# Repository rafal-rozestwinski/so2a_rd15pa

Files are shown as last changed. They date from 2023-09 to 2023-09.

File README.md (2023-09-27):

# so2a_rd15pa

Go to the [FULL BOARD](v1/so2a_rd15_pa_v1/) or [MINIMAL BOARD](v1/so2a_rd15_pa_v1-minimal/)

## Images

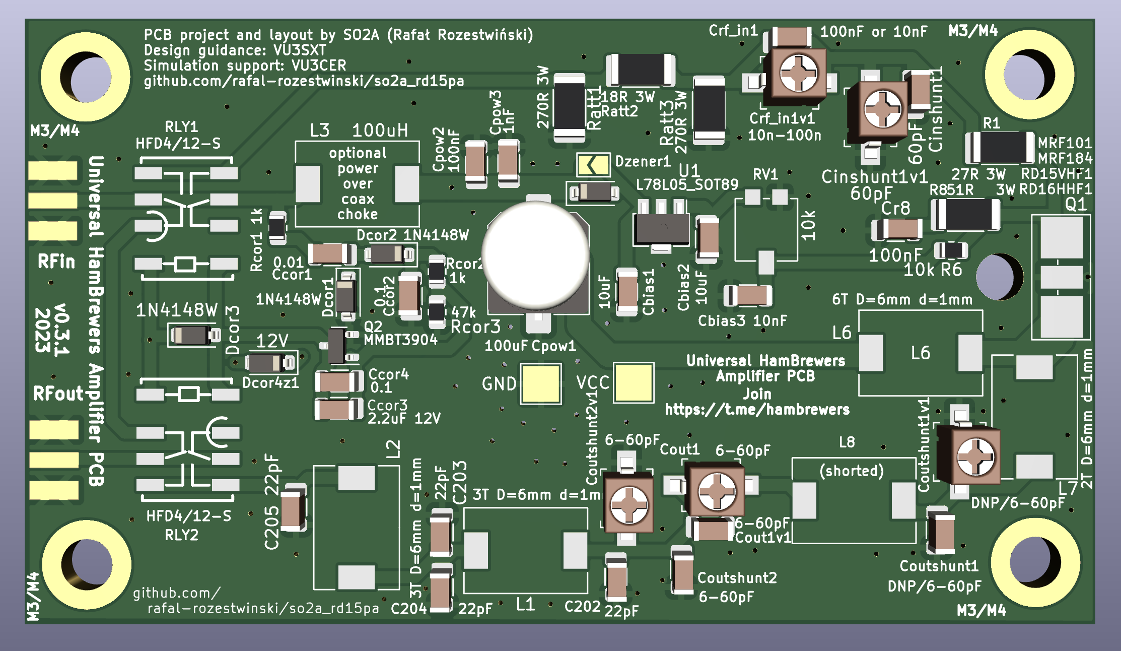
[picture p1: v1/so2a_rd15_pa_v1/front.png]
front


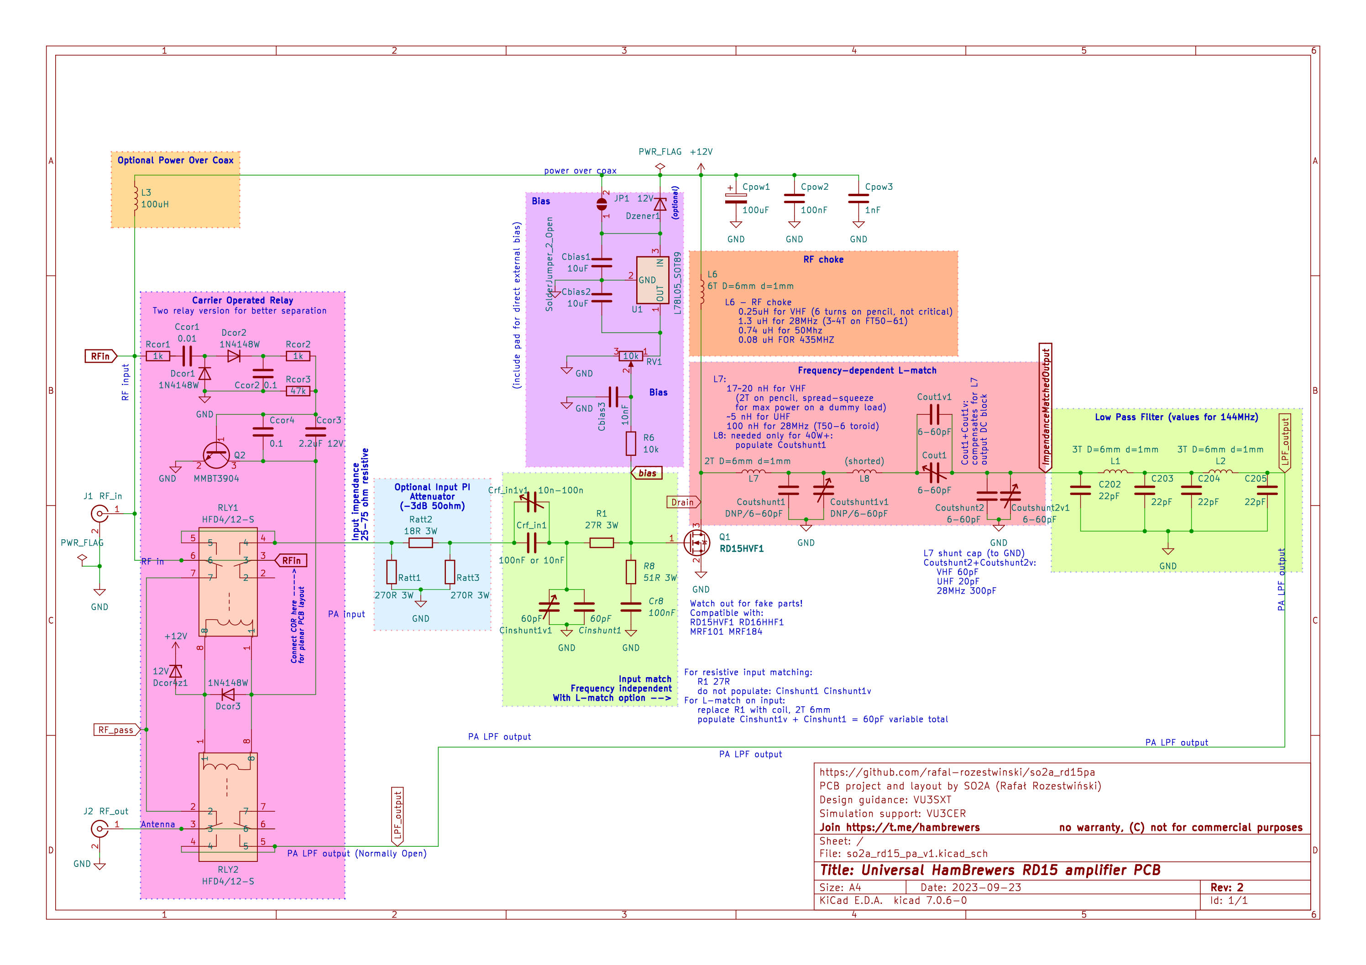
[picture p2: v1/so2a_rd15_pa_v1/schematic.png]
schematic


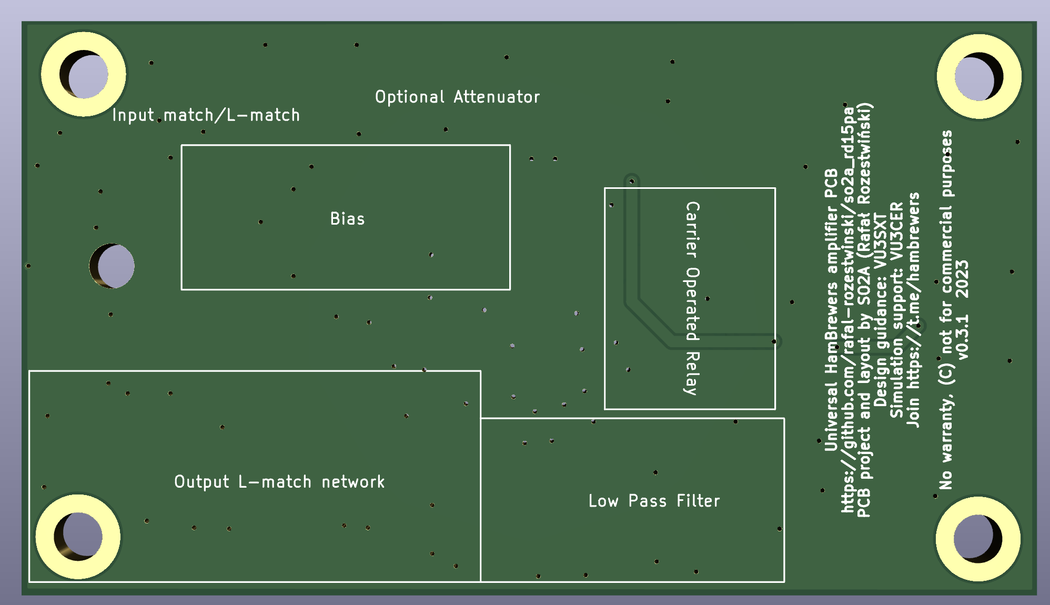
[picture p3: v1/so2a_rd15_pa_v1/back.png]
back


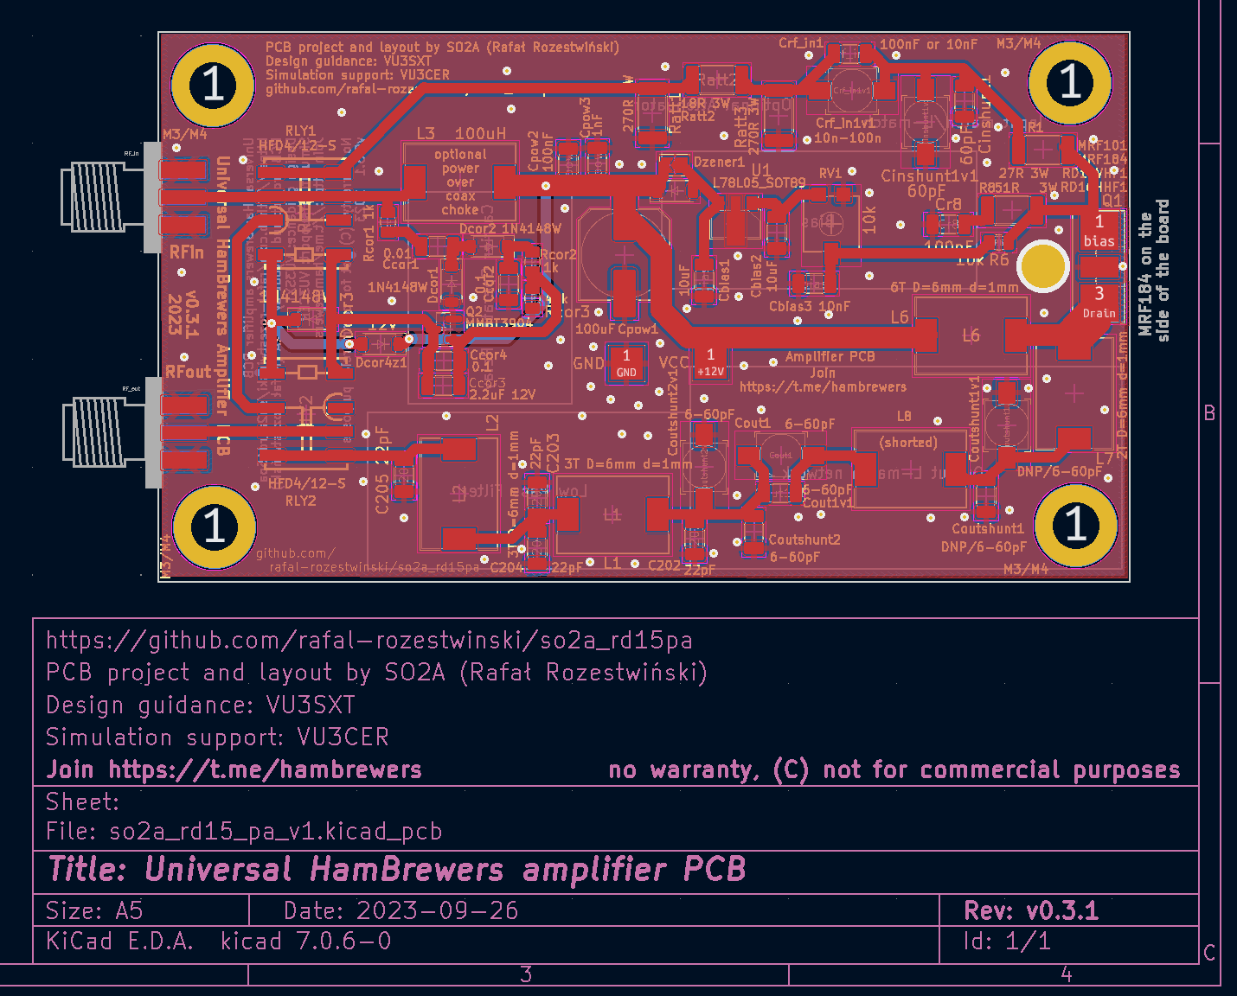
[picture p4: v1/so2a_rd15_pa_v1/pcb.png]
pcb


## Join HamBrewers on Telegram:

http://t.me/hambrewers

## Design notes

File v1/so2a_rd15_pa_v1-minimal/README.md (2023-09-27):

# so2a_rd15pa - MINIMAL

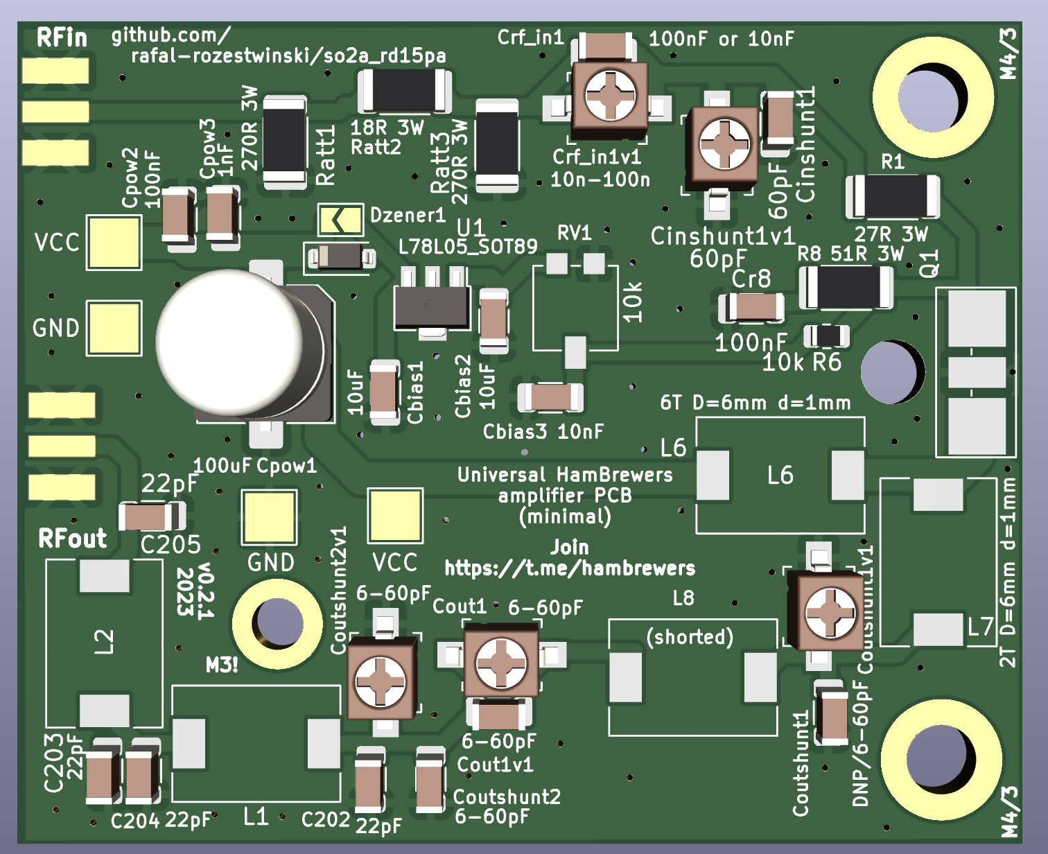
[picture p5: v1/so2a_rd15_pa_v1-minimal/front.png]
front


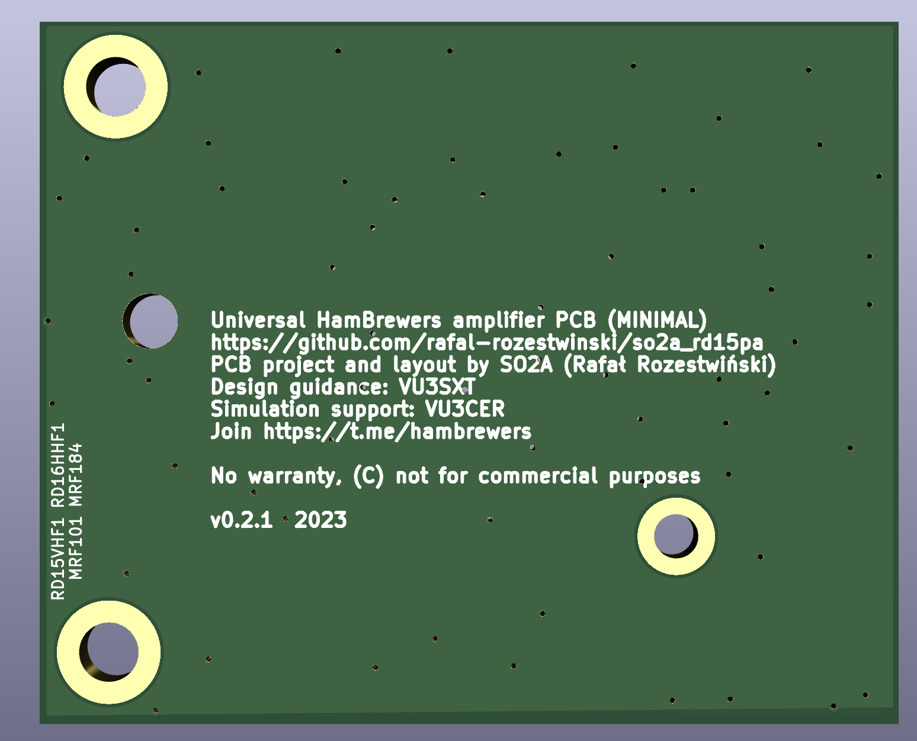
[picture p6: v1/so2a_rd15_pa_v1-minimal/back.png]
back


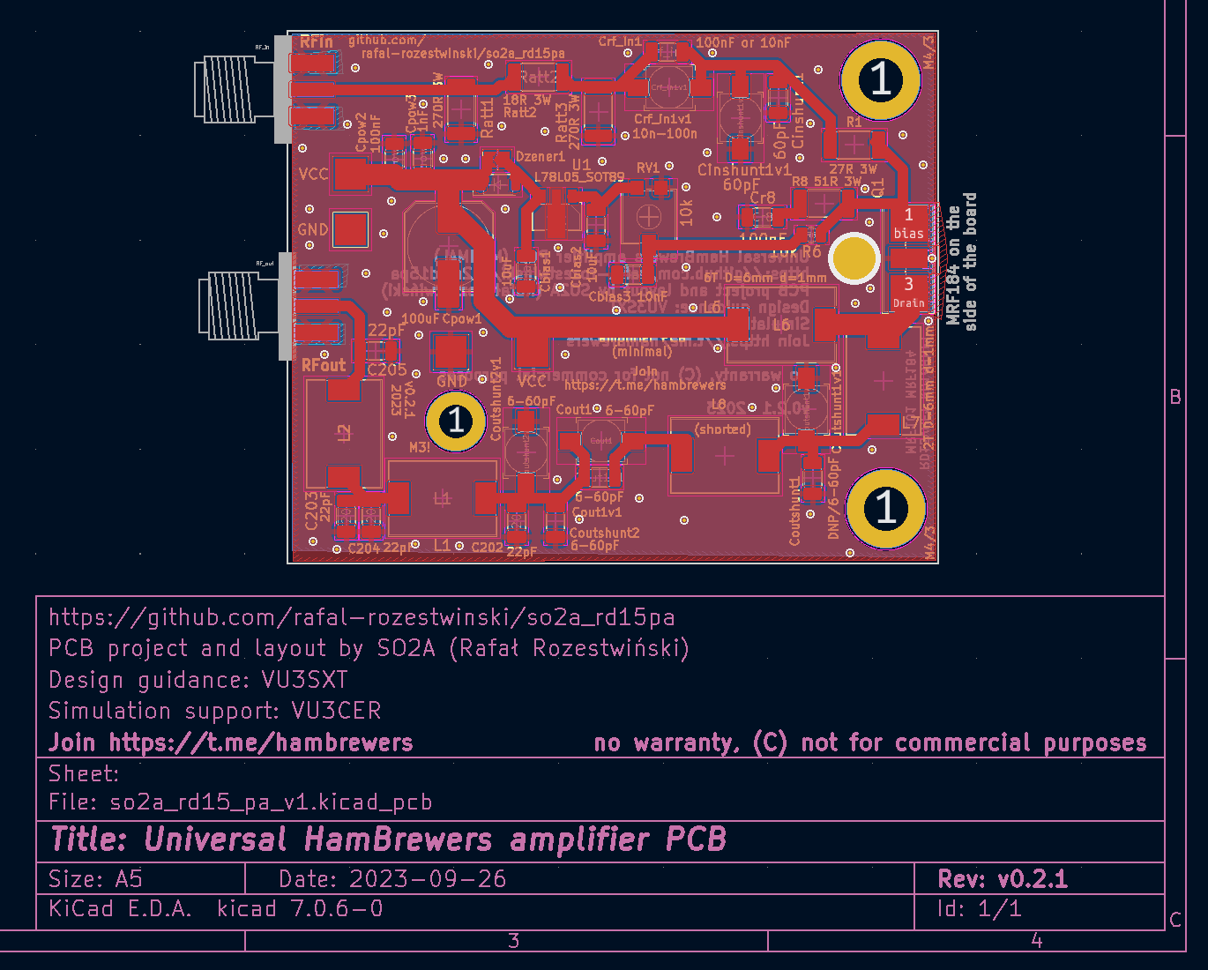
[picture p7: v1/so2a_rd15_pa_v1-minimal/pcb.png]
pcb


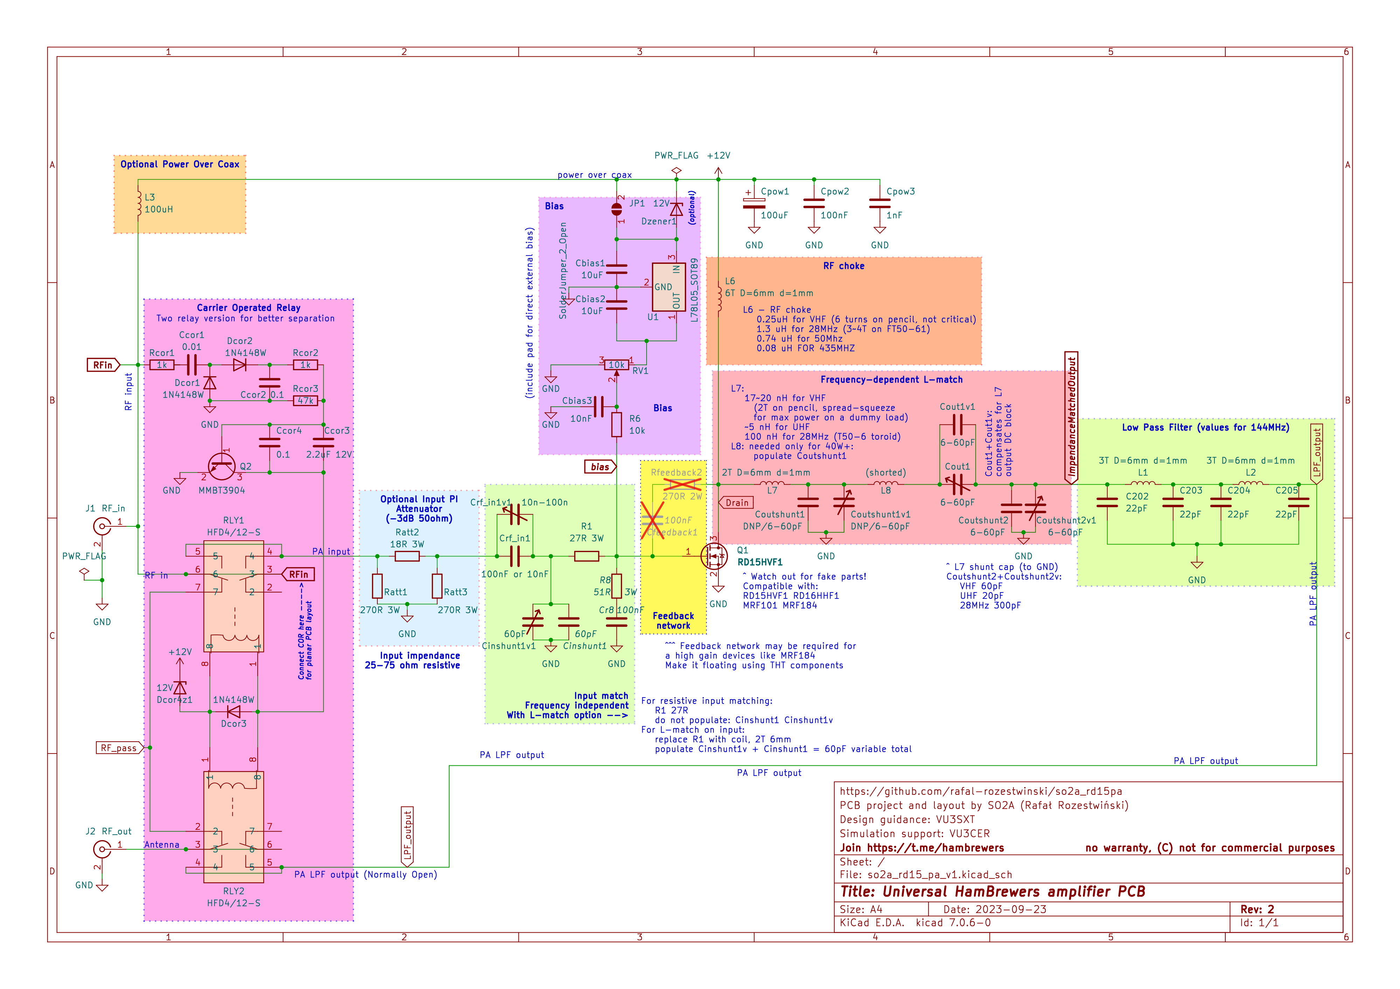
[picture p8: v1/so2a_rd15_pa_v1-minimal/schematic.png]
schematic


## Join HamBrewers on Telegram:

http://t.me/hambrewers

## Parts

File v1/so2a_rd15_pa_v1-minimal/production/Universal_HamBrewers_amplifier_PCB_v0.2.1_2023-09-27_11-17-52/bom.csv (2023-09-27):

Designator | Footprint | Quantity | Value | LCSC Part #
C202, C203, C204, C205 | 1206 | 4 | 22pF
Cbias1, Cbias2 | 1206 | 2 | 10uF
Cbias3 | 1206 | 1 | 10nF
Cinshunt1 | 1206 | 1 | 60pF
Cinshunt1v1 | C_Trimmer_Murata_TZB4-B | 1 | 60pF
Cout1, Coutshunt2v1 | C_Trimmer_Murata_TZB4-B | 2 | 6-60pF
Cout1v1, Coutshunt2 | 1206 | 2 | 6-60pF
Coutshunt1 | 1206 | 1 | DNP/6-60pF
Coutshunt1v1 | C_Trimmer_Murata_TZB4-B | 1 | DNP/6-60pF
Cpow1 | C_Elec_8x10.2 | 1 | 100uF
Cpow2, Cr8 | 1206 | 2 | 100nF
Cpow3 | 1206 | 1 | 1nF
Crf_in1 | 1206 | 1 | 100nF or 10nF
Crf_in1v1 | C_Trimmer_Murata_TZB4-B | 1 | 10n-100n
Dzener1 | D_SOD-123 | 1 | 12V
J1 | SMA_EDGELAUNCH_Modded | 1 | RF_in
J2 | SMA_EDGELAUNCH_Modded | 1 | RF_out
JP1 | SolderJumper-2_P1.3mm_Open_TrianglePad1.0x1.5mm | 1 | SolderJumper_2_Open
L1, L2 | L_Wuerth_HCM-1050 | 2 | 3T D=6mm d=1mm
L6 | L_Wuerth_HCM-1050 | 1 | 6T D=6mm d=1mm
L7 | L_Wuerth_HCM-1050 | 1 | 2T D=6mm d=1mm
L8 | L_Wuerth_HCM-1050 | 1 | (shorted)
Q1 | SO2A_TO-220F-3_Vertical_SMD | 1 | RD15HVF1
R1 | 2010 | 1 | 27R 3W
R6 | 0805 | 1 | 10k
R8 | 2010 | 1 | 51R 3W
RV1 | Potentiometer_Vishay_TS53YL_Vertical | 1 | 10k
Ratt1, Ratt3 | 2010 | 2 | 270R 3W
Ratt2 | 2010 | 1 | 18R 3W
U1 | SOT-89-3 | 1 | L78L05_SOT89

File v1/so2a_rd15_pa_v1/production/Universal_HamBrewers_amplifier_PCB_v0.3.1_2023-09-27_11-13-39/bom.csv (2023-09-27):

Designator | Footprint | Quantity | Value | LCSC Part #
C202, C203, C204, C205 | 1206 | 4 | 22pF
Cbias1, Cbias2 | 1206 | 2 | 10uF
Cbias3 | 1206 | 1 | 10nF
Ccor1 | 1206 | 1 | 0.01
Ccor2, Ccor4 | 1206 | 2 | 0.1
Ccor3 | 1206 | 1 | 2.2uF 12V
Cinshunt1 | 1206 | 1 | 60pF
Cinshunt1v1 | C_Trimmer_Murata_TZB4-B | 1 | 60pF
Cout1, Coutshunt2v1 | C_Trimmer_Murata_TZB4-B | 2 | 6-60pF
Cout1v1, Coutshunt2 | 1206 | 2 | 6-60pF
Coutshunt1 | 1206 | 1 | DNP/6-60pF
Coutshunt1v1 | C_Trimmer_Murata_TZB4-B | 1 | DNP/6-60pF
Cpow1 | C_Elec_8x10.2 | 1 | 100uF
Cpow2, Cr8 | 1206 | 2 | 100nF
Cpow3 | 1206 | 1 | 1nF
Crf_in1 | 1206 | 1 | 100nF or 10nF
Crf_in1v1 | C_Trimmer_Murata_TZB4-B | 1 | 10n-100n
Dcor1, Dcor2, Dcor3 | D_SOD-123 | 3 | 1N4148W
Dcor4z1, Dzener1 | D_SOD-123 | 2 | 12V
J1 | SMA_EDGELAUNCH_Modded | 1 | RF_in
J2 | SMA_EDGELAUNCH_Modded | 1 | RF_out
JP1 | SolderJumper-2_P1.3mm_Open_TrianglePad1.0x1.5mm | 1 | SolderJumper_2_Open
L1, L2 | L_Wuerth_HCM-1050 | 2 | 3T D=6mm d=1mm
L3 | L_Wuerth_HCM-1050 | 1 | 100uH
L6 | L_Wuerth_HCM-1050 | 1 | 6T D=6mm d=1mm
L7 | L_Wuerth_HCM-1050 | 1 | 2T D=6mm d=1mm
L8 | L_Wuerth_HCM-1050 | 1 | (shorted)
Q1 | SO2A_TO-220F-3_Vertical_SMD | 1 | RD15HVF1
Q2 | SOT-23 | 1 | MMBT3904
R1 | 2010 | 1 | 27R 3W
R6 | 0805 | 1 | 10k
R8 | 2010 | 1 | 51R 3W
RLY1, RLY2 | RELAY-SMD_HFD4-XX-SR | 2 | HFD4/12-S | C44212
RV1 | Potentiometer_Vishay_TS53YL_Vertical | 1 | 10k
Ratt1, Ratt3 | 2010 | 2 | 270R 3W
Ratt2 | 2010 | 1 | 18R 3W
Rcor1, Rcor2 | 0805 | 2 | 1k
Rcor3 | 0805 | 1 | 47k
U1 | SOT-89-3 | 1 | L78L05_SOT89

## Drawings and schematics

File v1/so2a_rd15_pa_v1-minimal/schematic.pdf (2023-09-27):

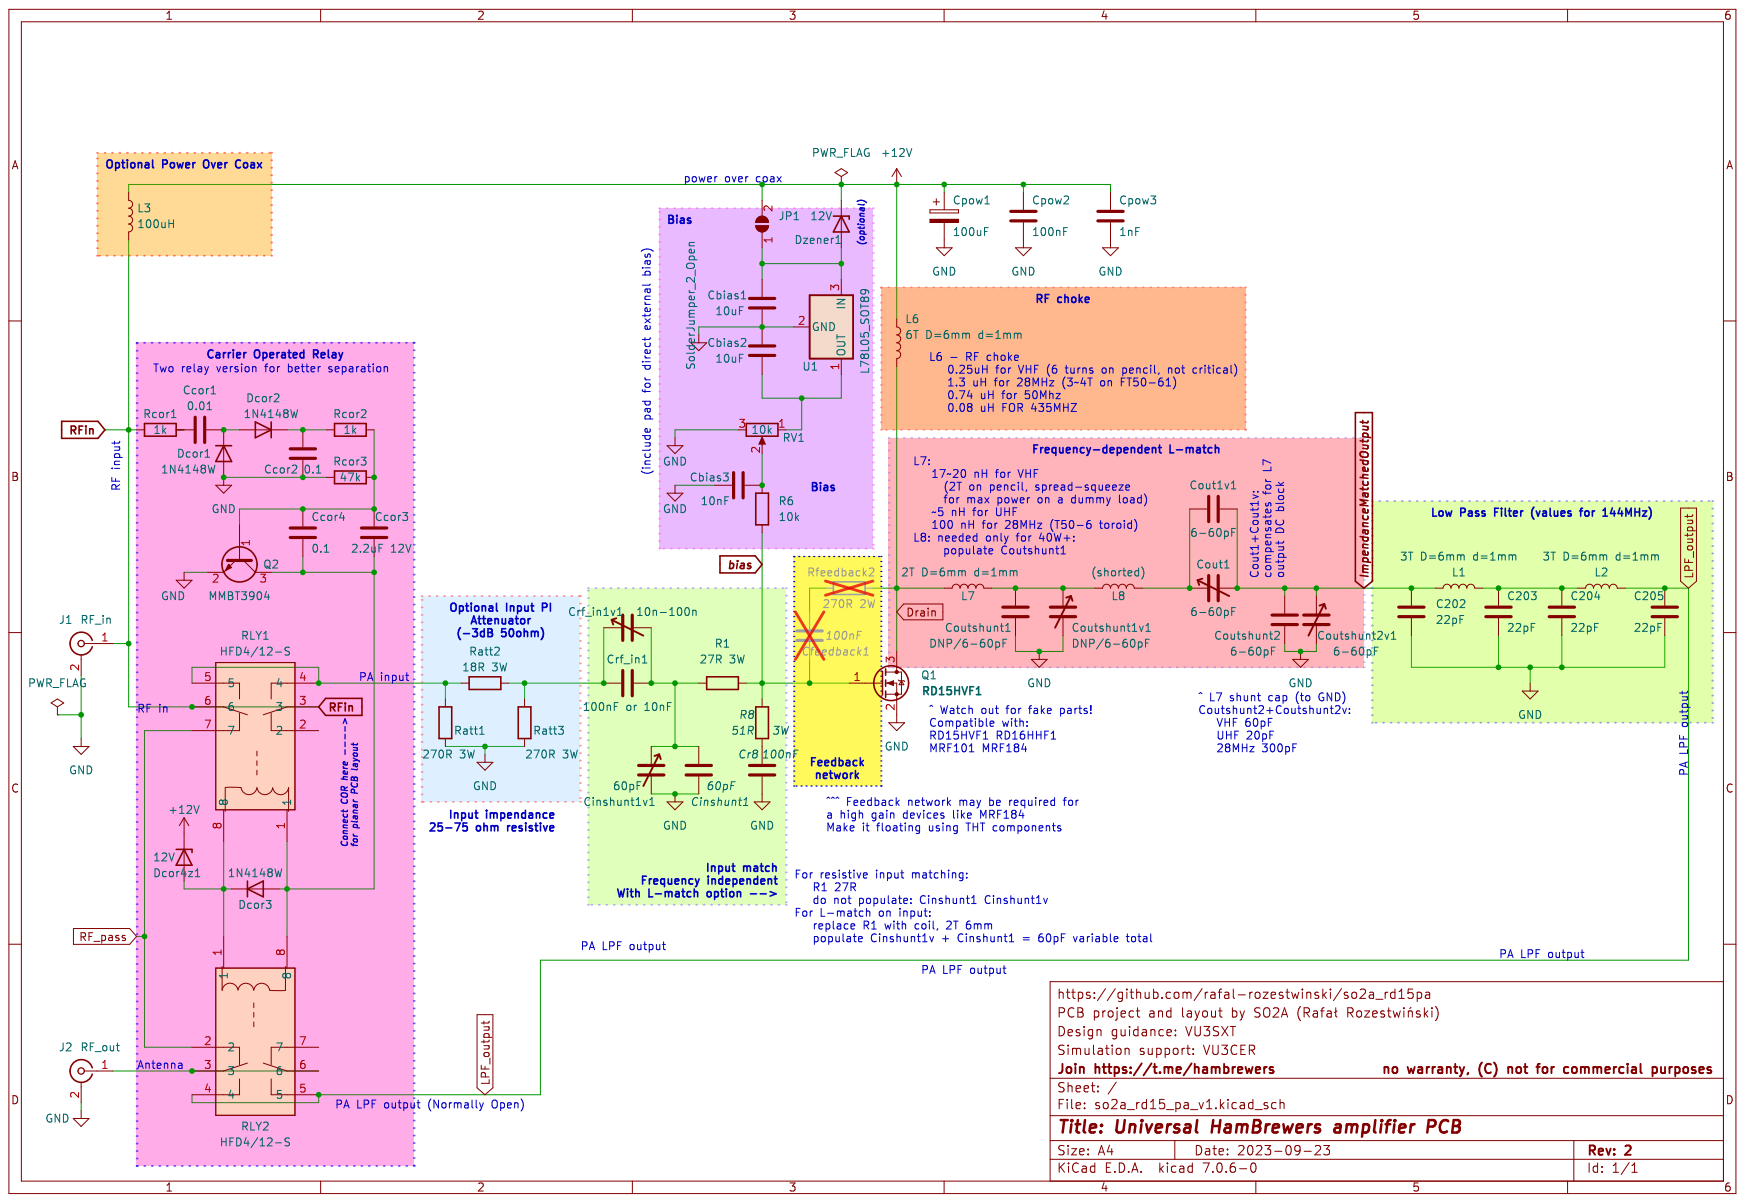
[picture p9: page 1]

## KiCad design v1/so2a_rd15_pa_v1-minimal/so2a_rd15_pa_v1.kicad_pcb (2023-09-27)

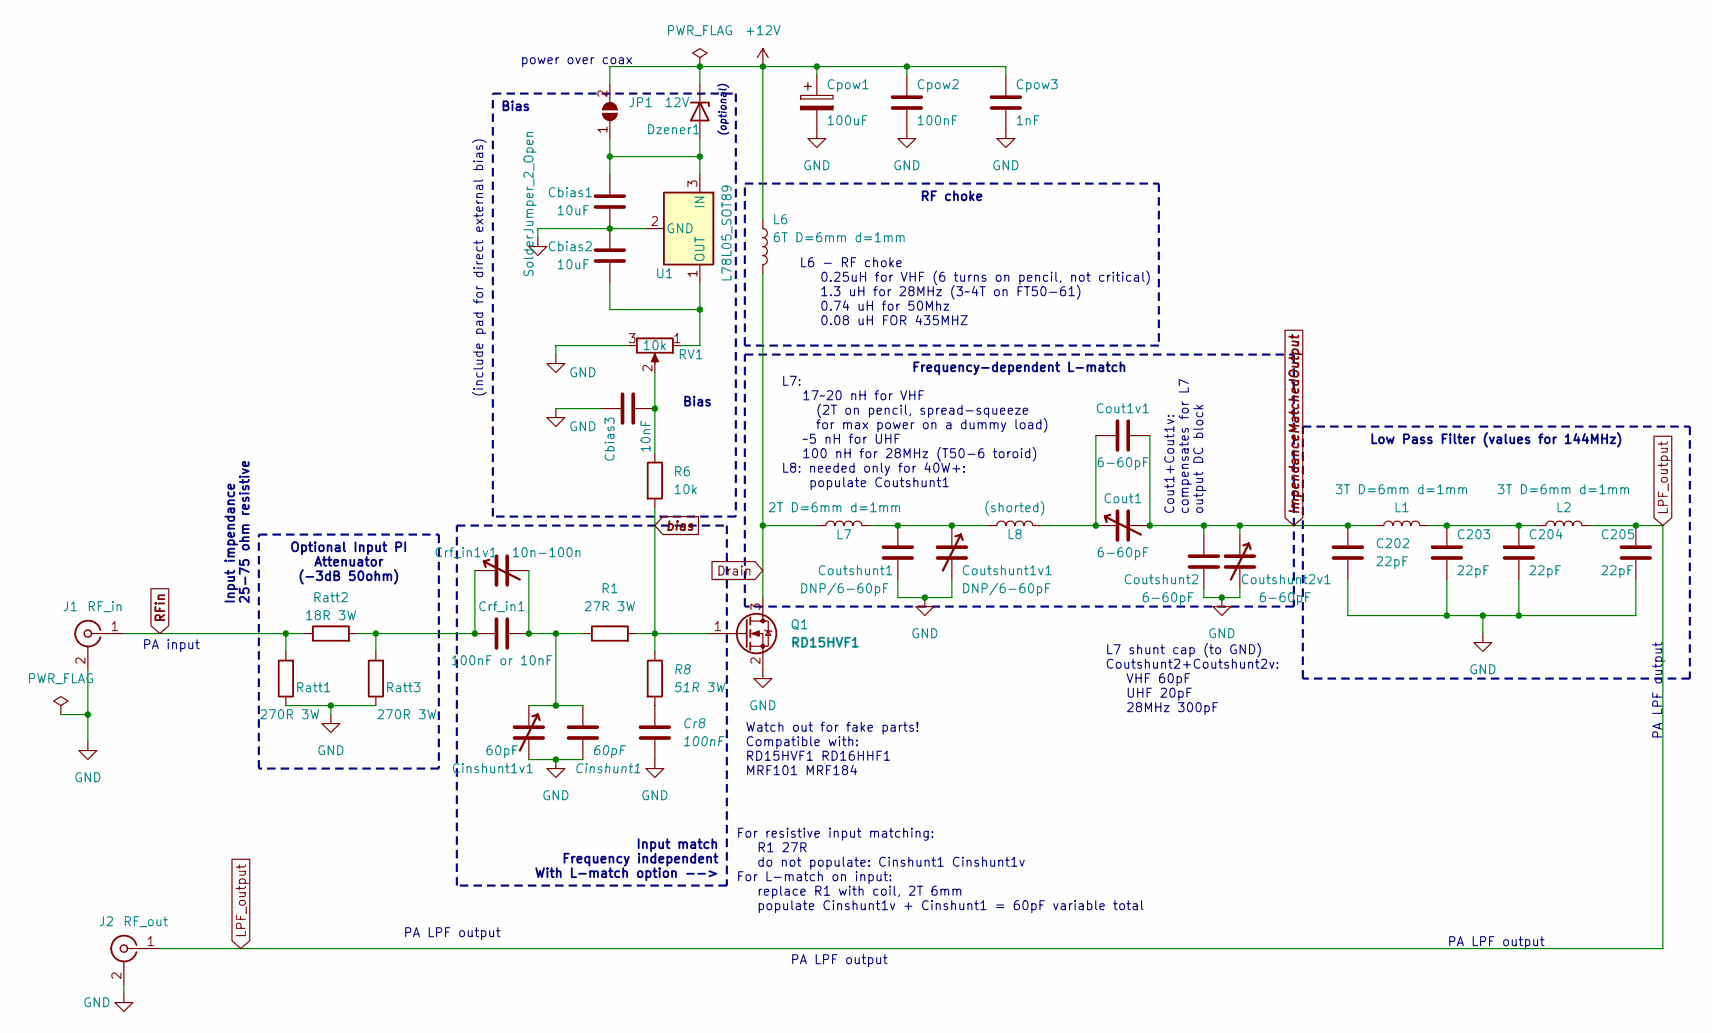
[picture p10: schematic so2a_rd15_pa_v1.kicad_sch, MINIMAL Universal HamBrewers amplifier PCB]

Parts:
C202, C203, C204, C205: 22pF; C_1206_3216Metric
Cbias1, Cbias2: 10uF; C_1206_3216Metric
Cbias3: 10nF; C_1206_3216Metric
Cinshunt1: 60pF; C_1206_3216Metric
Cinshunt1v1: 60pF; C_Trimmer_Murata_TZB4-B
Cout1: 6-60pF; C_Trimmer_Murata_TZB4-B
Cout1v1: 6-60pF; C_1206_3216Metric
Coutshunt1: DNP/6-60pF; C_1206_3216Metric
Coutshunt1v1: DNP/6-60pF; C_Trimmer_Murata_TZB4-B
Coutshunt2: 6-60pF; C_1206_3216Metric
Coutshunt2v1: 6-60pF; C_Trimmer_Murata_TZB4-B
Cpow1: 100uF; C_Elec_8x10.2
Cpow2: 100nF; C_1206_3216Metric
Cpow3: 1nF; C_1206_3216Metric
Cr8: 100nF; C_1206_3216Metric
Crf_in1: 100nF or 10nF; C_1206_3216Metric
Crf_in1v1: 10n-100n; C_Trimmer_Murata_TZB4-B
Dzener1: 12V; D_SOD-123
J1: RF_in; SMA_EDGELAUNCH_Modded
J2: RF_out; SMA_EDGELAUNCH_Modded
JP1: SolderJumper_2_Open; SolderJumper-2_P1.3mm_Open_TrianglePad1.0x1.5mm
L1, L2: 3T D=6mm d=1mm; L_Wuerth_HCM-1050
L6: 6T D=6mm d=1mm; L_Wuerth_HCM-1050
L7: 2T D=6mm d=1mm; L_Wuerth_HCM-1050
L8: (shorted); L_Wuerth_HCM-1050
Q1: RD15HVF1; SO2A_TO-220F-3_Vertical_SMD
R1: 27R 3W; R_2010_5025Metric
R6: 10k; R_0805_2012Metric
R8: 51R 3W; R_2010_5025Metric
RV1: 10k; Potentiometer_Vishay_TS53YL_Vertical
Ratt1, Ratt3: 270R 3W; R_2010_5025Metric
Ratt2: 18R 3W; R_2010_5025Metric
U1: L78L05_SOT89; SOT-89-3

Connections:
+12V: Cpow1.1, Cpow2.1, Cpow3.1, Dzener1.1 (K), JP1.2 (B), L6.1; also elsewhere on the board
Drain: L6.2, L7.1, Q1.3 (D)
GND: C202.1, C203.1, C204.1, C205.1, Cbias1.2, Cbias2.1, Cbias3.1, Cinshunt1.1, Cinshunt1v1.2, Coutshunt1.1, Coutshunt1v1.2, Coutshunt2.1, Coutshunt2v1.2, Cpow1.2, Cpow2.2, Cpow3.2, Cr8.1, J1.2 (Ext), J2.2 (Ext), Q1.2 (S), RV1.3, Ratt1.1, Ratt3.1, U1.2 (GND); also elsewhere on the board
ImpendanceMatchedOutput: C202.2, Cout1.2, Cout1v1.1, Coutshunt2.2, Coutshunt2v1.1, L1.1
LPF_output: C205.2, J2.1 (In), L2.2
unnamed: C203.2, C204.2, L1.2, L2.1
unnamed: Cbias3.2, R6.1, RV1.2
unnamed: Cinshunt1.2, Cinshunt1v1.1, Crf_in1.2, Crf_in1v1.2, R1.1
unnamed: Cout1.1, Cout1v1.2, L8.2
unnamed: Coutshunt1.2, Coutshunt1v1.1, L7.2, L8.1
unnamed: Cr8.2, R8.2
unnamed: Crf_in1.1, Crf_in1v1.1, Ratt2.2, Ratt3.2
unnamed: Cbias1.1, Dzener1.2 (A), JP1.1 (A), U1.3 (IN)
unnamed: Cbias2.2, RV1.1, U1.1 (OUT)
RFin: J1.1 (In), Ratt1.2, Ratt2.1
bias: Q1.1 (G), R1.2, R6.2, R8.1

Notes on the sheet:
Frequency-dependent L-match
Bias
Low Pass Filter (values for 144MHz)
Input match Frequency independent With L-match option -->
Optional Input PI Attenuator (-3dB 50ohm)
RF choke
Watch out for fake parts! Compatible with: RD15HVF1 RD16HHF1 MRF101 MRF184
Input impendance 25-75 ohm resistive
PA LPF output
For resistive input matching: R1 27R do not populate: Cinshunt1 Cinshunt1v For L-match on input: replace R1 with coil, 2T 6mm populate Cinshunt1v + Cinshunt1 = 60pF variable total
PA input
L6 - RF choke 0.25uH for VHF (6 turns on pencil, not critical) 1.3 uH for 28MHz (3~4T on FT50-61) 0.74 uH for 50Mhz 0.08 uH FOR 435MHZ
(include pad for direct external bias)
Cout1+Cout1v: compensates for L7 output DC block
power over coax
L7 shunt cap (to GND) Coutshunt2+Coutshunt2v: VHF 60pF UHF 20pF 28MHz 300pF
(optional)
L7: 17~20 nH for VHF (2T on pencil, spread-squeeze for max power on a dummy load) ~5 nH for UHF 100 nH for 28MHz (T50-6 toroid) L8: needed only for 40W+: populate Coutshunt1

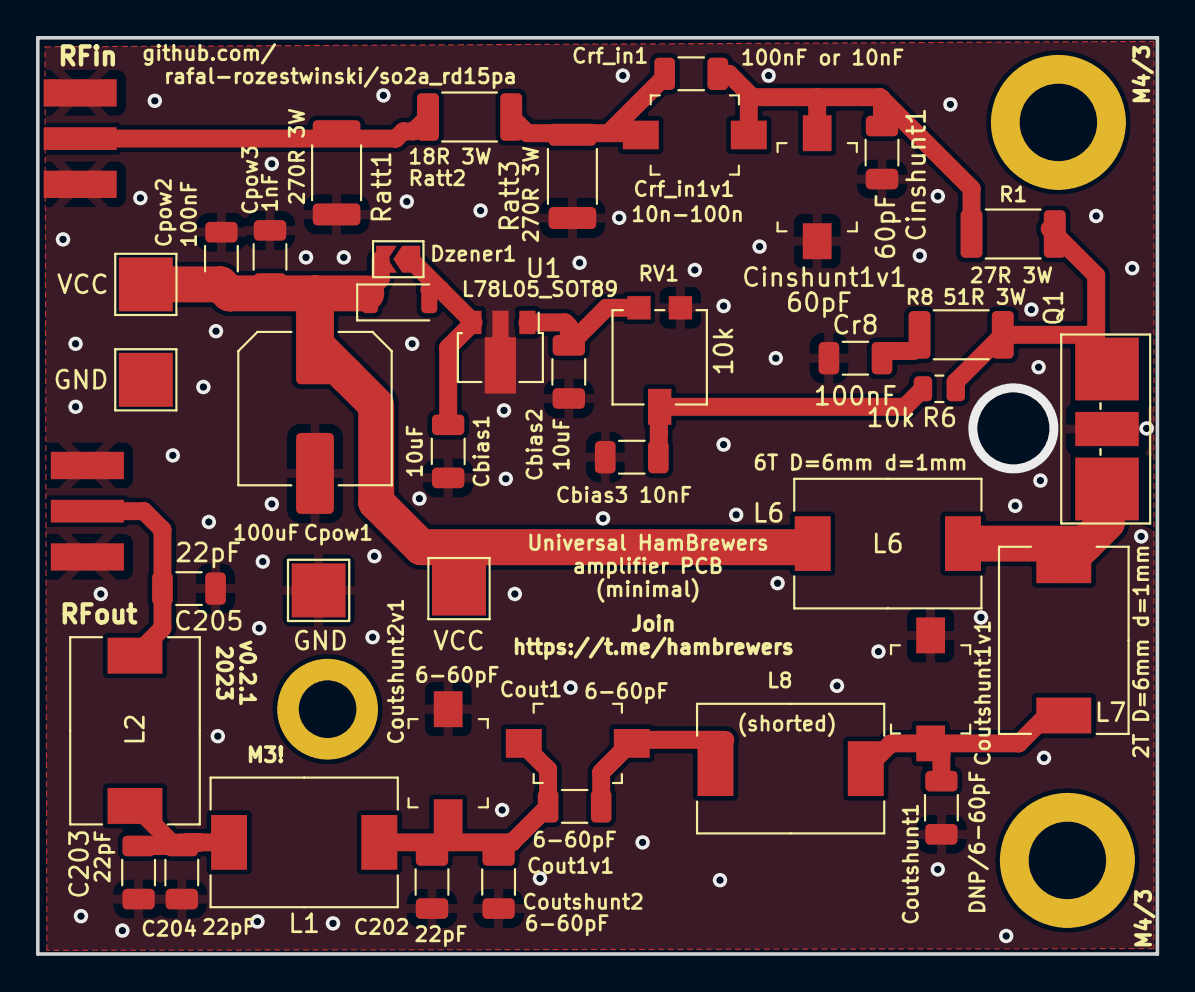
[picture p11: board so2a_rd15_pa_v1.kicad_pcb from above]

Board: 2 copper layers, 62.2 x 50.9 mm, 43 parts (0 on the bottom side), 16 nets.

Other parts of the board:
GND: TestPoint_Pad_3.0x3.0mm
GND#2: TestPoint_Pad_3.0x3.0mm
VCC: TestPoint_Pad_3.0x3.0mm
VCC#2: TestPoint_Pad_3.0x3.0mm

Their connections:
+12V: VCC.1, VCC#2.1; also elsewhere on the board
GND: GND.1; also elsewhere on the board

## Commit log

2023-09-27 v0.3.1: Adding minimal board; changes for the drain trace width
    [bom.csv, designators.csv, positions.csv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]
2023-09-27 incubator - switching push pull ucc for 80m
    [bom.csv, designators.csv, positions.csv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]
